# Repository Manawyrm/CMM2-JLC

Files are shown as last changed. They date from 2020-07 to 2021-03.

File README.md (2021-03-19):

Colour Maximite 2 - JLC-ready design
=============================
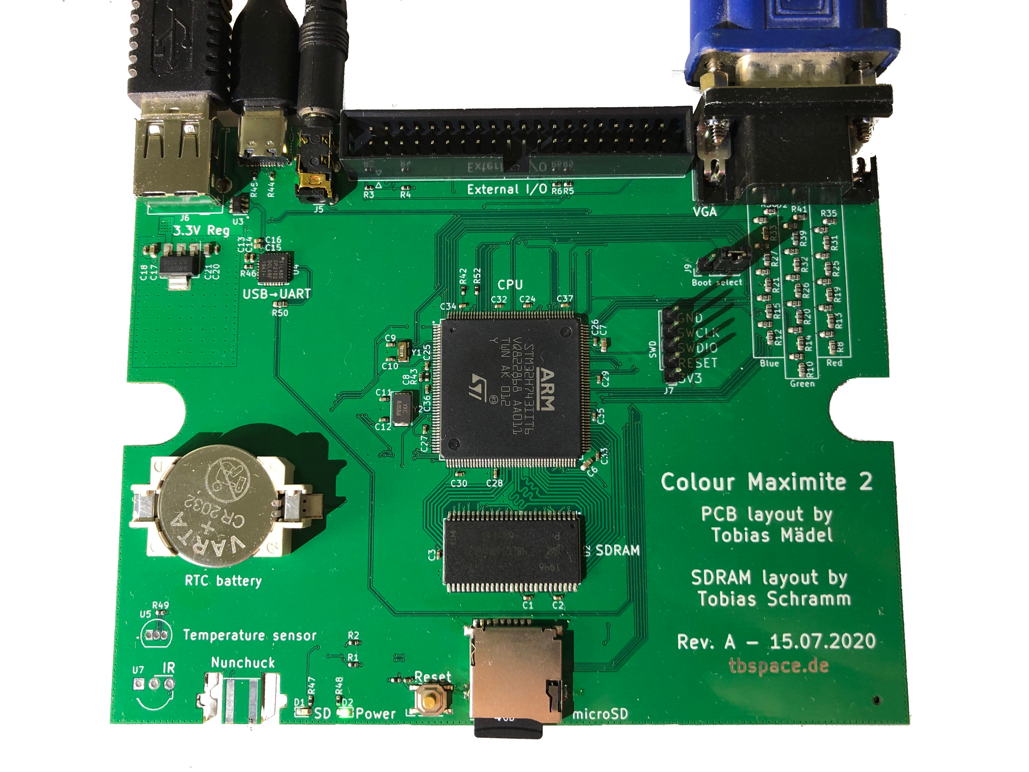
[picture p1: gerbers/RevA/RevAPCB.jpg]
PCB


#### Overview

This is a open-source hardware clone PCB of the [Colour Maximite 2](https://geoffg.net/maximite.html) computer.  
It's fully compatible to the original firmware and software.  

- Designed for automated assembly at [JLCPCB](https://jlcpcb.com/DDE), everything except the connectors can be machine assembled.  
- USB-C port (instead of USB-B) for serial and power  
- microSD socket instead of full-size SD socket  
- STM32 and SDRAM directly onboard, no expensive evaluation board needed  

#### Bill of materials

[Interactive BOM](https://tbspace.de/content/downloads/ibom_cmm2_reve.html)

| Description | Part No.  | Links  |
| :---:|---| -----:|
| 3.5mm audio jack | XKB PJ-3270 | [LCSC](https://lcsc.com/product-detail/Audio-Video-Connectors_XKB-Connectivity-PJ-3270_C381134.html) |
| microSD socket | HOAUC HYC77-TF09-200 | [LCSC](https://lcsc.com/product-detail/Card-Sockets-Connectors_HOAUC-HYC77-TF09-200_C341092.html)  |
| USB-C connector | Jing C167321 | [LCSC](https://lcsc.com/product-detail/USB-Connectors_Jing-Extension-of-the-Electronic-Co-C167321_C167321.html)  |
| USB-A connector | Jing C42650 | [LCSC](https://lcsc.com/product-detail/USB-Connectors_Jing-Extension-of-the-Electronic-Co-C42650_C42650.html)  |
| 40pin IDC | BOOMELE C9138 | [LCSC](https://lcsc.com/product-detail/IDC-Connectors_BOOMELE-Boom-Precision-Elec-C9138_C9138.html)  |
| VGA connector | CONNFLY DS1038-15FBNSiA74-0CC | [LCSC](https://lcsc.com/product-detail/D-Sub-Connectors_CONNFLY-Elec-DS1038-15FBNSiA74-0CC_C75754.html)  |

#### Footprint credits
| Author | Components  |
| ----- |---|
| [Tobias Schramm](https://github.com/TobleMiner) | CR2032 Holder, 3.5mm Audiojack, MicroSD socket, reset button |
| [Jan Henrik Hemsing](https://github.com/Jan--Henrik) | Nunchuck connector |

#### Rev.A Errata
- Missing mounting holes
- SDRAM pinout is missing A12 line 
(causes instability, fixed in Rev.B, workaround with enamelled copper wire of the same length as the other traces)
- SRV05 diode package had the Pin 1 indicator at Pin 6.  
- Nunchuck footprint is reversed

#### Rev. B Errata
- KiCad Bug caused data corruption in PCB files, board files were reset back to pre-RevA state (missing via stitching). Will still work. 
- SRV05 diode package had the Pin 1 indicator at Pin 6.  
- Nunchuck footprint is reversed

#### Rev. C Errata
- SRV05 diode package had the Pin 1 indicator at Pin 6.  
- Nunchuck footprint is reversed

#### Rev. D Errata
- SRV05 diode package had the Pin 1 indicator at Pin 6.

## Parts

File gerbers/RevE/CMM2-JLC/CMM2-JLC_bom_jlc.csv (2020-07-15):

Comment | Designator | Footprint | LCSC Part #
CR2032 | BT1 | BatteryHolder_CR2032-BS-6-1 | C70377
100n | C1,C2,C3,C4,C5,C14,C16,C20,C18,C22,C23,C24,C25,C26,C27,C28,C29,C30,C31,C32,C33,C34,C35,C36,C37 | C_0402_1005Metric | C1525
2.2u | C6,C7 | C_0603_1608Metric | C23630
6p | C9,C10 | C_0402_1005Metric | C30274
20p | C11,C12 | C_0402_1005Metric | C1554
1u | C13,C8,C19 | C_0402_1005Metric | C52923
4.7u | C15 | C_0402_1005Metric | C23733
10u | C17 | C_0603_1608Metric | C19702
22u | C21 | C_0603_1608Metric | C59461
SD CARD / RED | D1 | LED_0603_1608Metric | C2286
POWER / GREEN | D2 | LED_0603_1608Metric | C72043
10k | R1,R2,R3,R4,R5,R6,R42,R52 | R_0402_1005Metric | C25744
240R | R7,R16,R22,R28,R8,R34,R11,R18,R24,R30,R12,R37,R9,R17,R23,R29,R10,R40,R36 | R_0603_1608Metric | C23350
120R | R13,R19,R25,R31,R15,R21,R27,R33,R14,R20,R26,R39,R32,R50 | R_0603_1608Metric | C22787
75R | R35,R38,R41 | R_0603_1608Metric | C4275
10R | R43 | R_0402_1005Metric | C25077
5.1k | R44,R45 | R_0402_1005Metric | C25905
3.3k | R47 | R_0402_1005Metric | C25890
4.7k | R48,R49,R46 | R_0402_1005Metric | C25900
100k | R51 | R_0402_1005Metric | C25741
Reset | SW1 | TS-1187A-X-X-X | C318887
STM32H743IITx | U1 | LQFP-176_24x24mm_P0.5mm | C89597
MT48LC16M16A2P | U2 | TSOP-II-54_22.2x10.16mm_P0.8mm | C26393
SRV05-4 | U3 | SOT-23-6 | C85364
CP2102N-A01-GQFN28 | U4 | QFN-28-1EP_5x5mm_P0.5mm_EP3.35x3.35mm | C6568
AMS1117-3.3 | U6 | SOT-223-3_TabPin2 | C6186
32.768 kHz | Y1 | Crystal_SMD_3215-2Pin_3.2x1.5mm | C32346
8 MHz | Y2 | Crystal_SMD_5032-2Pin_5.0x3.2mm | C115962

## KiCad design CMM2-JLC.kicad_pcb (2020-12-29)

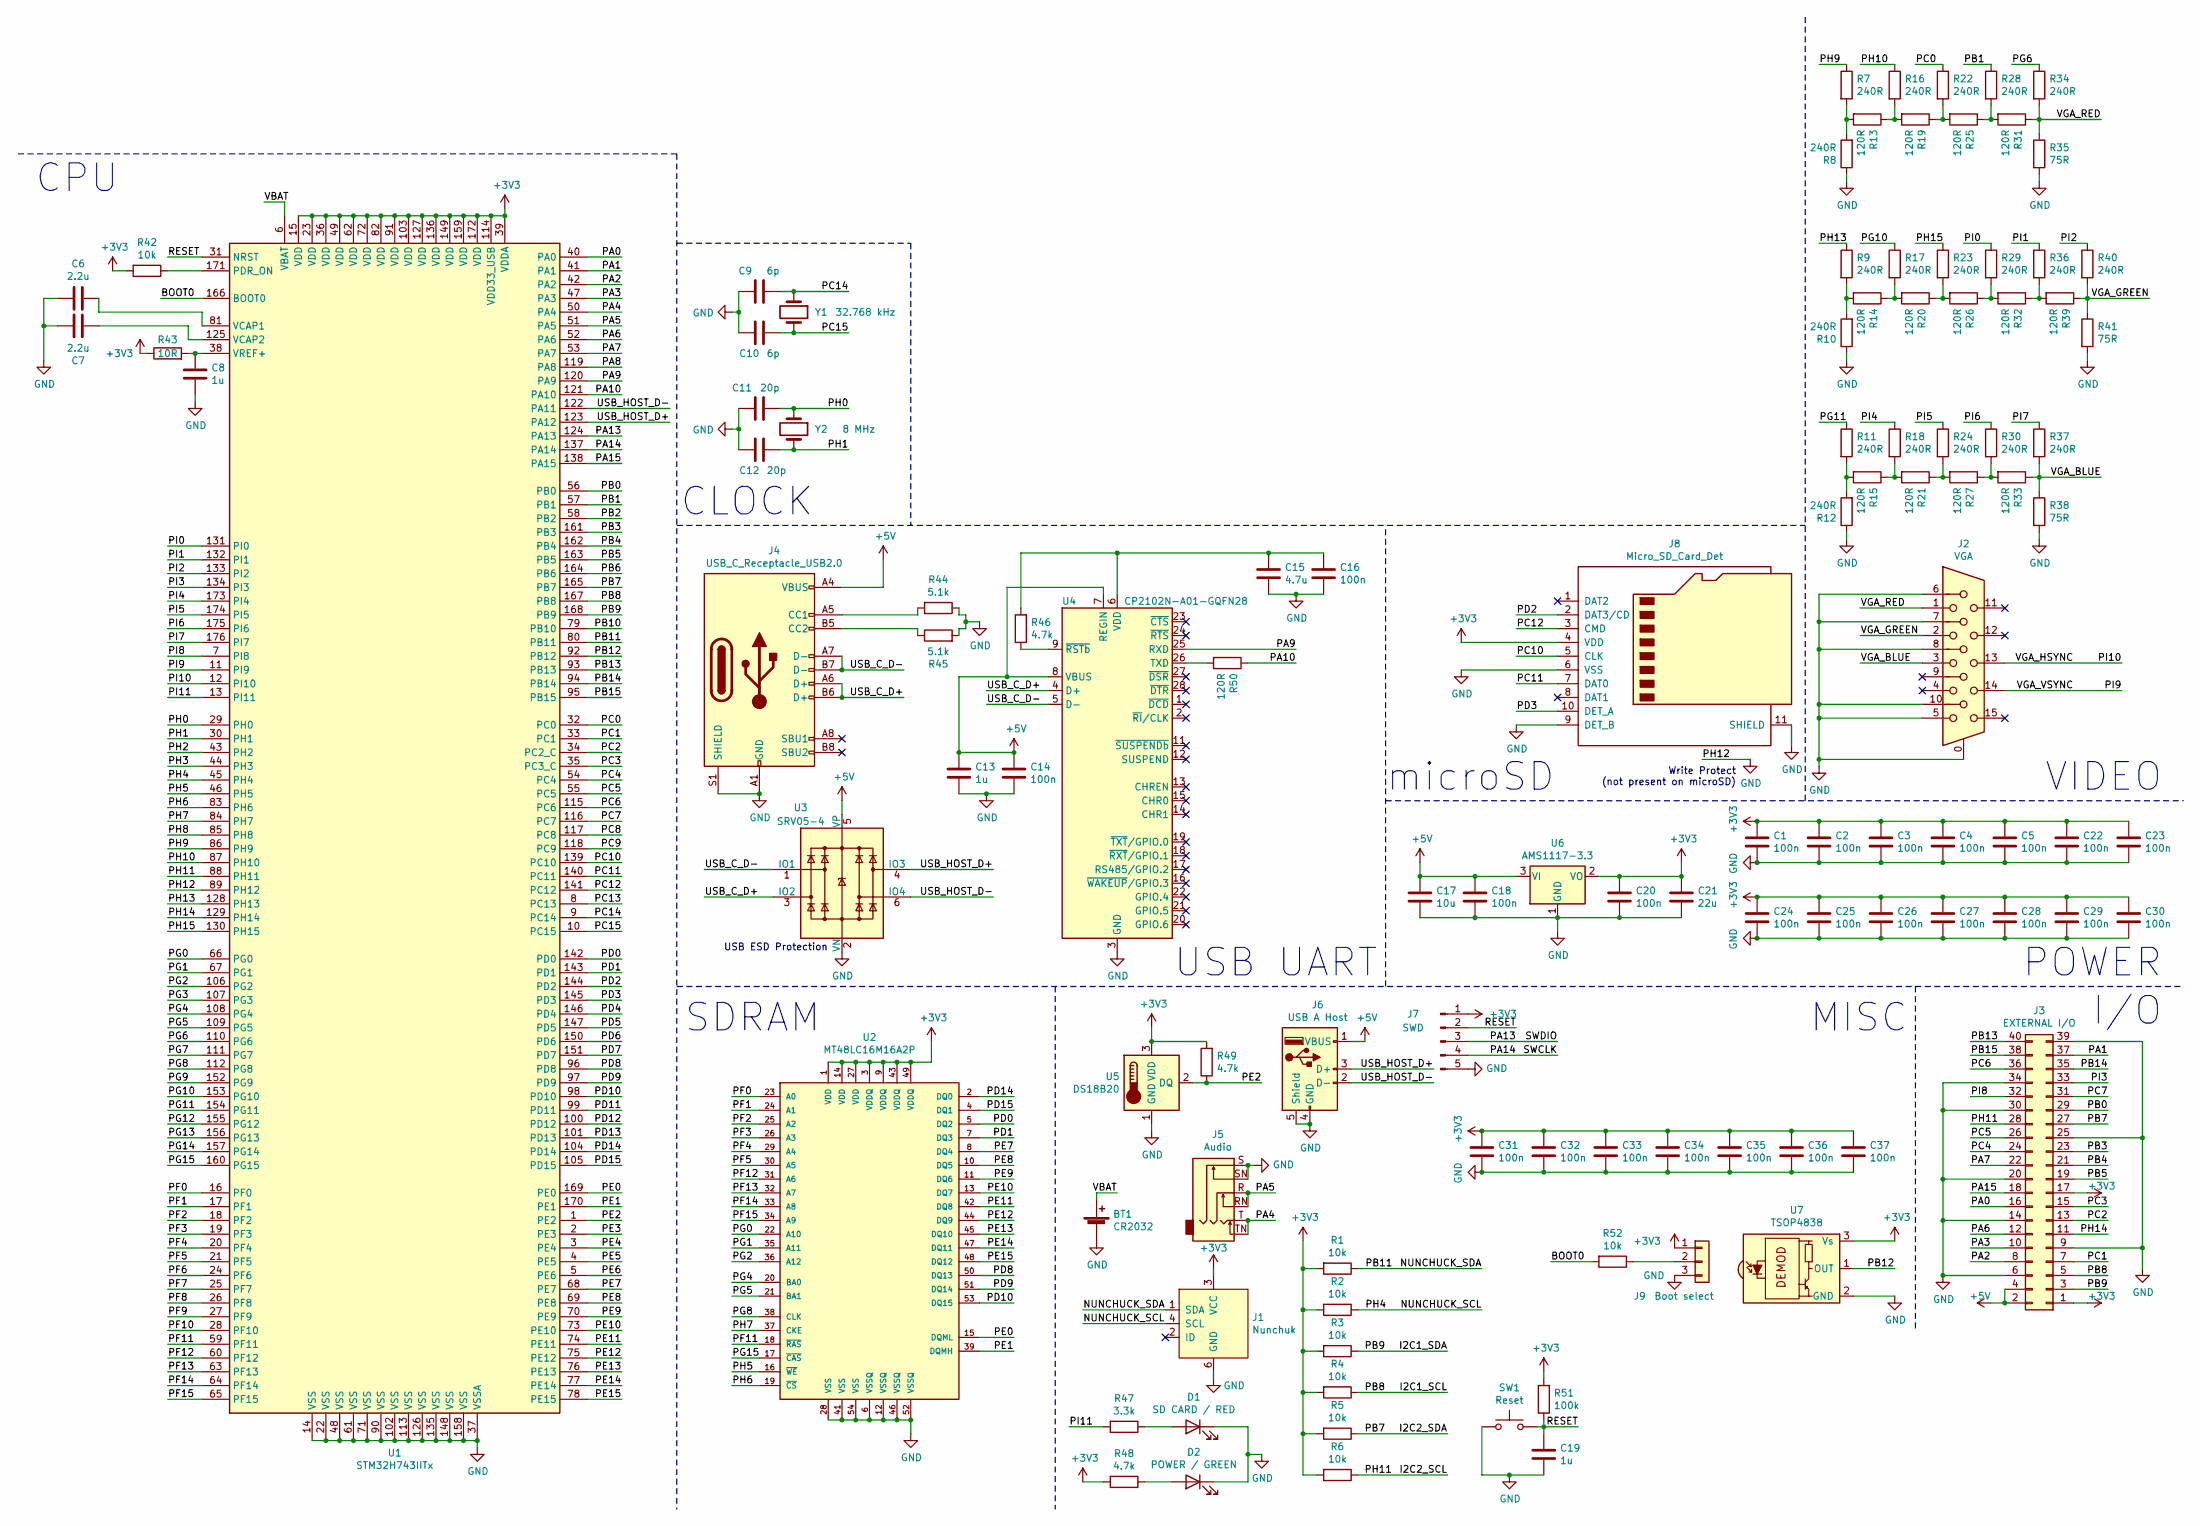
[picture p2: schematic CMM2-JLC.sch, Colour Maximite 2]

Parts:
BT1: CR2032; BatteryHolder_CR2032-BS-6-1; LCSC C70377
C1, C2, C3, C4, C5, C14, C16, C18, C20, C22, C23, C24, C25, C26, C27, C28, C29, C30, C31, C32, C33, C34, C35, C36, C37: 100n; C_0402_1005Metric; LCSC C1525
C6, C7: 2.2u; C_0603_1608Metric; LCSC C23630
C8, C13, C19: 1u; C_0402_1005Metric; LCSC C52923
C9, C10: 6p; C_0402_1005Metric; LCSC C30274
C11, C12: 20p; C_0402_1005Metric; LCSC C1554
C15: 4.7u; C_0402_1005Metric; LCSC C23733
C17: 10u; C_0603_1608Metric; LCSC C19702
C21: 22u; C_0603_1608Metric; LCSC C59461
D1: SD CARD / RED; LED_0603_1608Metric; LCSC C2286
D2: POWER / GREEN; LED_0603_1608Metric; LCSC C72043
J1: Nunchuk; nunchuck
J2: VGA; DSUB-15-HD_Female_Horizontal_P2.29x2,54mm_EdgePinOffset8.63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
J3: EXTERNAL I/O; IDC-Header_2x20_P2.54mm_Vertical
J4: USB_C_Receptacle_USB2.0; USB_C_Receptacle_Palconn_UTC16-G
J5: Audio; PJ-3270
J6: USB A Host; USB_A_Molex_67643_Horizontal
J7: SWD; PinHeader_1x05_P2.54mm_Vertical
J8: Micro_SD_Card_Det; HOAUC_HYC77-TF09-200
J9: Boot select; PinHeader_1x03_P2.54mm_Vertical
R1, R2, R3, R4, R5, R6, R42, R52: 10k; R_0402_1005Metric; LCSC C25744
R7, R8, R9, R10, R11, R12, R16, R17, R18, R22, R23, R24, R28, R29, R30, R34, R36, R37, R40: 240R; R_0603_1608Metric; LCSC C23350
R13, R14, R15, R19, R20, R21, R25, R26, R27, R31, R32, R33, R39, R50: 120R; R_0603_1608Metric; LCSC C22787
R35, R38, R41: 75R; R_0603_1608Metric; LCSC C4275
R43: 10R; R_0402_1005Metric; LCSC C25077
R44, R45: 5.1k; R_0402_1005Metric; LCSC C25905
R46, R48, R49: 4.7k; R_0402_1005Metric; LCSC C25900
R47: 3.3k; R_0402_1005Metric; LCSC C25890
R51: 100k; R_0402_1005Metric; LCSC C25741
SW1: Reset; TS-1187A-X-X-X; LCSC C318887
U1: STM32H743IITx; LQFP-176_24x24mm_P0.5mm; LCSC C89597
U2: MT48LC16M16A2P; TSOP-II-54_22.2x10.16mm_P0.8mm; LCSC C26393
U3: SRV05-4; SOT-23-6; LCSC C85364
U4: CP2102N-A01-GQFN28; QFN-28-1EP_5x5mm_P0.5mm_EP3.35x3.35mm; LCSC C6568
U5: DS18B20; TO-92_Inline
U6: AMS1117-3.3; SOT-223-3_TabPin2; LCSC C6186
U7: TSOP4838; Vishay_MOLD-3Pin
Y1: 32.768 kHz; Crystal_SMD_3215-2Pin_3.2x1.5mm; LCSC C32346
Y2: 8 MHz; Crystal_SMD_5032-2Pin_5.0x3.2mm; LCSC C115962

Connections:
+3V3: C1.1, C2.1, C3.1, C4.1, C5.1, C20.1, C21.1, C22.1, C23.1, C24.1, C25.1, C26.1, C27.1, C28.1, C29.1, C30.1, C31.1, C32.1, C33.1, C34.1, C35.1, C36.1, C37.1, J1.3 (VCC), J3.1, J3.17, J7.1, J8.4 (VDD), J9.1, R1.2, R2.2, R3.2, R4.2, R5.2, R6.2, R42.2, R43.1, R48.2, R49.2, R51.2, U1.15 (VDD), U1.23 (VDD), U1.36 (VDD), U1.39 (VDDA), U1.49 (VDD), U1.62 (VDD), U1.72 (VDD), U1.82 (VDD), U1.91 (VDD), U1.103 (VDD), U1.114 (VDD33_USB), U1.127 (VDD), U1.136 (VDD), U1.149 (VDD), U1.159 (VDD), U1.172 (VDD), U2.1 (VDD), U2.3 (VDDQ), U2.9 (VDDQ), U2.14 (VDD), U2.27 (VDD), U2.43 (VDDQ), U2.49 (VDDQ), U5.3 (VDD), U6.2 (VO), U7.3 (Vs)
+5V: C13.1, C14.1, C17.1, C18.1, J3.2, J3.4, J4.A4 (VBUS), J4.A9 (VBUS), J4.B4 (VBUS), J4.B9 (VBUS), J6.1 (VBUS), U3.5 (VP), U4.7 (REGIN), U4.8 (VBUS), U6.3 (VI)
/BOOT0: R52.2, U1.166 (BOOT0)
/I2C1_SCL: J3.5, R4.1, U1.167 (PB8)
/I2C1_SDA: J3.3, R3.1, U1.168 (PB9)
/I2C2_SCL: J3.28, R6.1, U1.88 (PH11)
/I2C2_SDA: J3.27, R5.1, U1.165 (PB7)
/NUNCHUCK_SCL: J1.4 (SCL), R2.1, U1.45 (PH4)
/NUNCHUCK_SDA: J1.1 (SDA), R1.1, U1.80 (PB11)
/PA0: J3.16, U1.40 (PA0)
/PA1: J3.37, U1.41 (PA1)
/PA2: J3.8, U1.42 (PA2)
/PA3: J3.10, U1.47 (PA3)
/PA4: J5.T, J5.TN, U1.50 (PA4)
/PA5: J5.R, J5.RN, U1.51 (PA5)
/PA6: J3.12, U1.52 (PA6)
/PA7: J3.22, U1.53 (PA7)
/PA8: U1.119 (PA8)
/PA9: U1.120 (PA9), U4.25 (RXD)
/PA10: R50.1, U1.121 (PA10)
/PA13: J7.3, U1.124 (PA13)
/PA14: J7.4, U1.137 (PA14)
/PA15: J3.18, U1.138 (PA15)
/PB0: J3.29, U1.56 (PB0)
/PB1: R28.1, U1.57 (PB1)
/PB2: U1.58 (PB2)
/PB3: J3.23, U1.161 (PB3)
/PB4: J3.21, U1.162 (PB4)
/PB5: J3.19, U1.163 (PB5)
/PB6: U1.164 (PB6)
/PB10: U1.79 (PB10)
/PB12: U1.92 (PB12), U7.1 (OUT)
/PB13: J3.40, U1.93 (PB13)
/PB14: J3.35, U1.94 (PB14)
/PB15: J3.38, U1.95 (PB15)
/PC0: R22.1, U1.32 (PC0)
/PC1: J3.7, U1.33 (PC1)
/PC2: J3.13, U1.34 (PC2_C)
/PC3: J3.15, U1.35 (PC3_C)
/PC4: J3.24, U1.54 (PC4)
/PC5: J3.26, U1.55 (PC5)
/PC6: J3.36, U1.115 (PC6)
/PC7: J3.31, U1.116 (PC7)
/PC8: U1.117 (PC8)
/PC9: U1.118 (PC9)
/PC10: J8.5 (CLK), U1.139 (PC10)
/PC11: J8.7 (DAT0), U1.140 (PC11)
/PC12: J8.3 (CMD), U1.141 (PC12)
/PC13: U1.8 (PC13)
/PC14: C9.2, U1.9 (PC14), Y1.1
/PC15: C10.1, U1.10 (PC15), Y1.2
/PD0: U1.142 (PD0), U2.5 (DQ2)
/PD1: U1.143 (PD1), U2.7 (DQ3)
/PD2: J8.2 (DAT3/CD), U1.144 (PD2)
/PD3: J8.10 (DET_A), U1.145 (PD3)
/PD4: U1.146 (PD4)
/PD5: U1.147 (PD5)
/PD6: U1.150 (PD6)
/PD7: U1.151 (PD7)
/PD8: U1.96 (PD8), U2.50 (DQ13)
/PD9: U1.97 (PD9), U2.51 (DQ14)
/PD10: U1.98 (PD10), U2.53 (DQ15)
/PD11: U1.99 (PD11)
/PD12: U1.100 (PD12)
/PD13: U1.101 (PD13)
/PD14: U1.104 (PD14), U2.2 (DQ0)
/PD15: U1.105 (PD15), U2.4 (DQ1)
/PE0: U1.169 (PE0), U2.15 (DQML)
/PE1: U1.170 (PE1), U2.39 (DQMH)
/PE2: R49.1, U1.1 (PE2), U5.2 (DQ)
/PE3: U1.2 (PE3)
/PE4: U1.3 (PE4)
/PE5: U1.4 (PE5)
/PE6: U1.5 (PE6)
/PE7: U1.68 (PE7), U2.8 (DQ4)
/PE8: U1.69 (PE8), U2.10 (DQ5)
/PE9: U1.70 (PE9), U2.11 (DQ6)
/PE10: U1.73 (PE10), U2.13 (DQ7)
/PE11: U1.74 (PE11), U2.42 (DQ8)
/PE12: U1.75 (PE12), U2.44 (DQ9)
/PE13: U1.76 (PE13), U2.45 (DQ10)
/PE14: U1.77 (PE14), U2.47 (DQ11)
/PE15: U1.78 (PE15), U2.48 (DQ12)
/PF0: U1.16 (PF0), U2.23 (A0)
/PF1: U1.17 (PF1), U2.24 (A1)
/PF2: U1.18 (PF2), U2.25 (A2)
/PF3: U1.19 (PF3), U2.26 (A3)
/PF4: U1.20 (PF4), U2.29 (A4)
/PF5: U1.21 (PF5), U2.30 (A5)
/PF6: U1.24 (PF6)
/PF7: U1.25 (PF7)
/PF8: U1.26 (PF8)
/PF9: U1.27 (PF9)
/PF10: U1.28 (PF10)
/PF11: U1.59 (PF11), U2.18 (~RAS~)
/PF12: U1.60 (PF12), U2.31 (A6)
/PF13: U1.63 (PF13), U2.32 (A7)
/PF14: U1.64 (PF14), U2.33 (A8)
/PF15: U1.65 (PF15), U2.34 (A9)
/PG0: U1.66 (PG0), U2.22 (A10)
/PG1: U1.67 (PG1), U2.35 (A11)
/PG2: U1.106 (PG2), U2.36 (A12)
/PG3: U1.107 (PG3)
/PG4: U1.108 (PG4), U2.20 (BA0)
/PG5: U1.109 (PG5), U2.21 (BA1)
/PG6: R34.1, U1.110 (PG6)
/PG7: U1.111 (PG7)
/PG8: U1.112 (PG8), U2.38 (CLK)
/PG9: U1.152 (PG9)
/PG10: R17.1, U1.153 (PG10)
/PG11: R11.1, U1.154 (PG11)
/PG12: U1.155 (PG12)
/PG13: U1.156 (PG13)
/PG14: U1.157 (PG14)
/PG15: U1.160 (PG15), U2.17 (~CAS~)
/PH0: C11.2, U1.29 (PH0), Y2.1
/PH1: C12.1, U1.30 (PH1), Y2.2
/PH2: U1.43 (PH2)
/PH3: U1.44 (PH3)
/PH5: U1.46 (PH5), U2.16 (~WE~)
/PH6: U1.83 (PH6), U2.19 (~CS~)
/PH7: U1.84 (PH7), U2.37 (CKE)
/PH8: U1.85 (PH8)
/PH9: R7.1, U1.86 (PH9)
/PH10: R16.1, U1.87 (PH10)
/PH13: R9.1, U1.128 (PH13)
/PH14: J3.11, U1.129 (PH14)
/PH15: R23.1, U1.130 (PH15)
/PI0: R29.1, U1.131 (PI0)
/PI1: R36.1, U1.132 (PI1)
/PI2: R40.1, U1.133 (PI2)
/PI3: J3.33, U1.134 (PI3)
/PI4: R18.1, U1.173 (PI4)
/PI5: R24.1, U1.174 (PI5)
/PI6: R30.1, U1.175 (PI6)
/PI7: R37.1, U1.176 (PI7)
/PI8: J3.32, U1.7 (PI8)
/PI9: J2.14, U1.11 (PI9)
/PI10: J2.13, U1.12 (PI10)
/PI11: R47.2, U1.13 (PI11)
/RESET: C19.1, J7.2, R51.1, SW1.2, U1.31 (NRST)
/USB_C_D+: J4.A6 (D+), J4.B6 (D+), U3.3 (IO2), U4.4 (D+)
/USB_C_D-: J4.A7 (D-), J4.B7 (D-), U3.1 (IO1), U4.5 (D-)
/USB_HOST_D+: J6.3 (D+), U1.123 (PA12), U3.4 (IO3)
/USB_HOST_D-: J6.2 (D-), U1.122 (PA11), U3.6 (IO4)
/VBAT: BT1.1 (+), U1.6 (VBAT)
/VGA_BLUE: J2.3, R33.1, R37.2, R38.1
/VGA_GREEN: J2.2, R39.1, R40.2, R41.1
/VGA_RED: J2.1, R31.1, R34.2, R35.1
GND: BT1.2 (-), C1.2, C2.2, C3.2, C4.2, C5.2, C6.2, C7.1, C8.2, C9.1, C10.2, C11.1, C12.2, C13.2, C14.2, C15.2, C16.2, C17.2, C18.2, C19.2, C20.2, C21.2, C22.2, C23.2, C24.2, C25.2, C26.2, C27.2, C28.2, C29.2, C30.2, C31.2, C32.2, C33.2, C34.2, C35.2, C36.2, C37.2, D1.1 (K), D2.1 (K), J1.6 (GND), J2.0, J2.5, J2.6, J2.7, J2.8, J2.10, J3.6, J3.9, J3.14, J3.20, J3.25, J3.30, J3.34, J3.39, J4.A1 (GND), J4.A12 (GND), J4.B1 (GND), J4.B12 (GND), J4.S1 (SHIELD), J5.S, J5.SN, J6.4 (GND), J6.5 (Shield), J7.5, J8.6 (VSS), J8.9 (DET_B), J8.11 (SHIELD), J9.3, R8.1, R10.1, R12.1, R35.2, R38.2, R41.2, R44.1, R45.2, SW1.1, U1.14 (VSS), U1.22 (VSS), U1.37 (VSSA), U1.48 (VSS), U1.61 (VSS), U1.71 (VSS), U1.89 (PH12), U1.90 (VSS), U1.102 (VSS), U1.113 (VSS), U1.126 (VSS), U1.135 (VSS), U1.148 (VSS), U1.158 (VSS), U2.6 (VSSQ), U2.12 (VSSQ), U2.28 (VSS), U2.41 (VSS), U2.46 (VSSQ), U2.52 (VSSQ), U2.54 (VSS), U3.2 (VN), U4.3 (GND), U4.29 (GND), U5.1 (GND), U6.1 (GND), U7.2 (GND)
unnamed: C6.1, U1.81 (VCAP1)
unnamed: C7.2, U1.125 (VCAP2)
unnamed: C8.1, R43.2, U1.38 (VREF+)
unnamed: C15.1, C16.1, R46.2, U4.6 (VDD)
unnamed: D1.2 (A), R47.1
unnamed: D2.2 (A), R48.1
unnamed: J4.A5 (CC1), R44.2
unnamed: J4.B5 (CC2), R45.1
unnamed: J9.2, R52.1
unnamed: R9.2, R10.2, R14.2
unnamed: R11.2, R12.2, R15.2
unnamed: R13.1, R16.2, R19.2
unnamed: R7.2, R8.2, R13.2
unnamed: R14.1, R17.2, R20.2
unnamed: R15.1, R18.2, R21.2
unnamed: R19.1, R22.2, R25.2
unnamed: R20.1, R23.2, R26.2
unnamed: R21.1, R24.2, R27.2
unnamed: R25.1, R28.2, R31.2
unnamed: R26.1, R29.2, R32.2
unnamed: R27.1, R30.2, R33.2
unnamed: R32.1, R36.2, R39.2
unnamed: R42.1, U1.171 (PDR_ON)
unnamed: R46.1, U4.9 (~RSTb)
unnamed: R50.2, U4.26 (TXD)

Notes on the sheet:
SDRAM
CPU
VIDEO
I/O
MISC
USB ESD Protection
USB UART
POWER
Write Protect (not present on microSD)
microSD
CLOCK

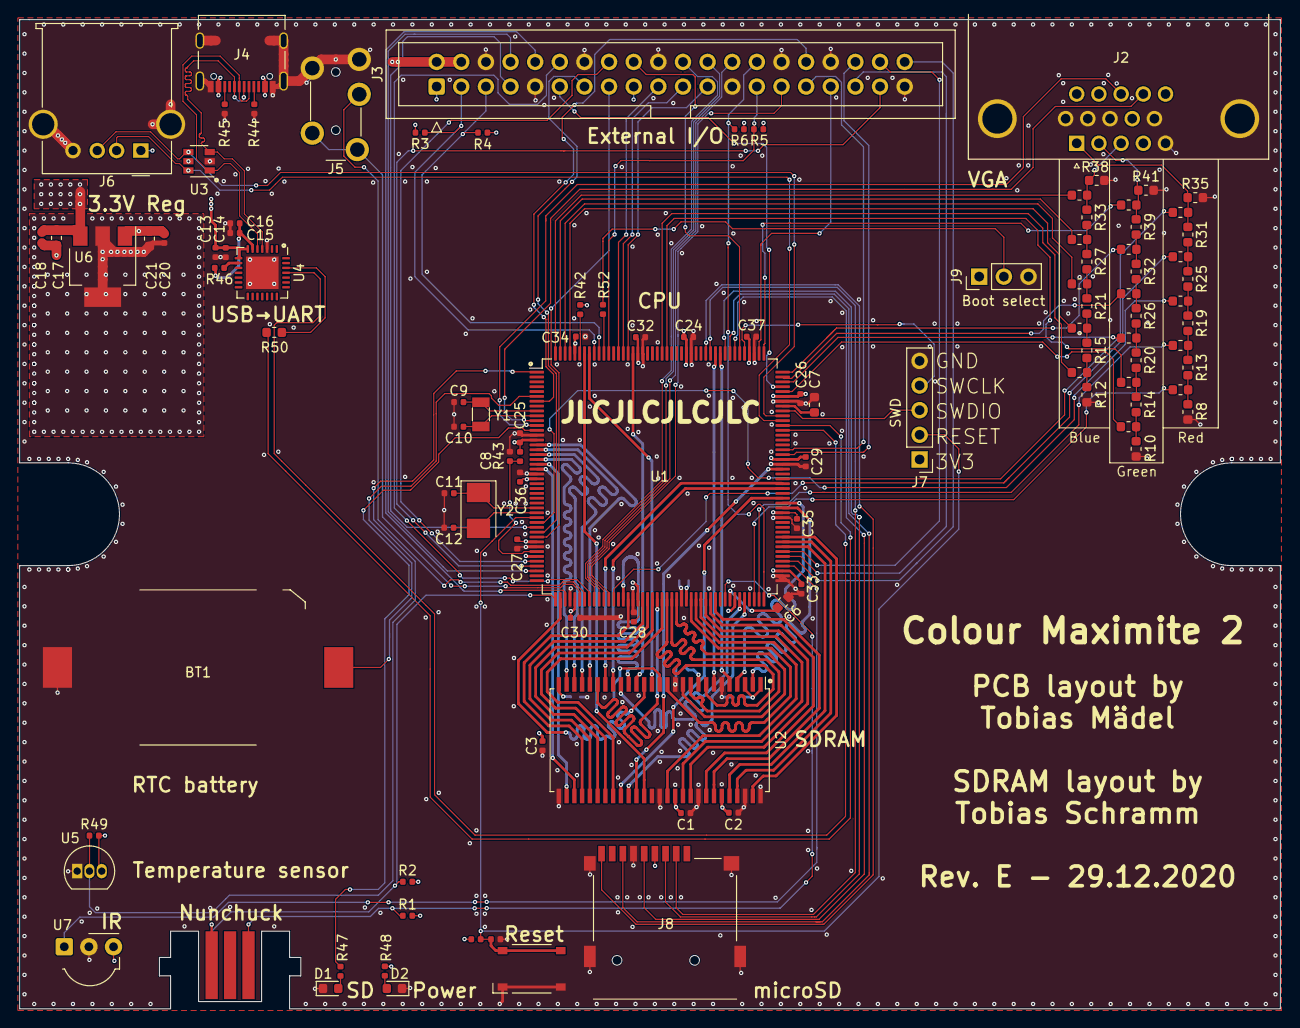
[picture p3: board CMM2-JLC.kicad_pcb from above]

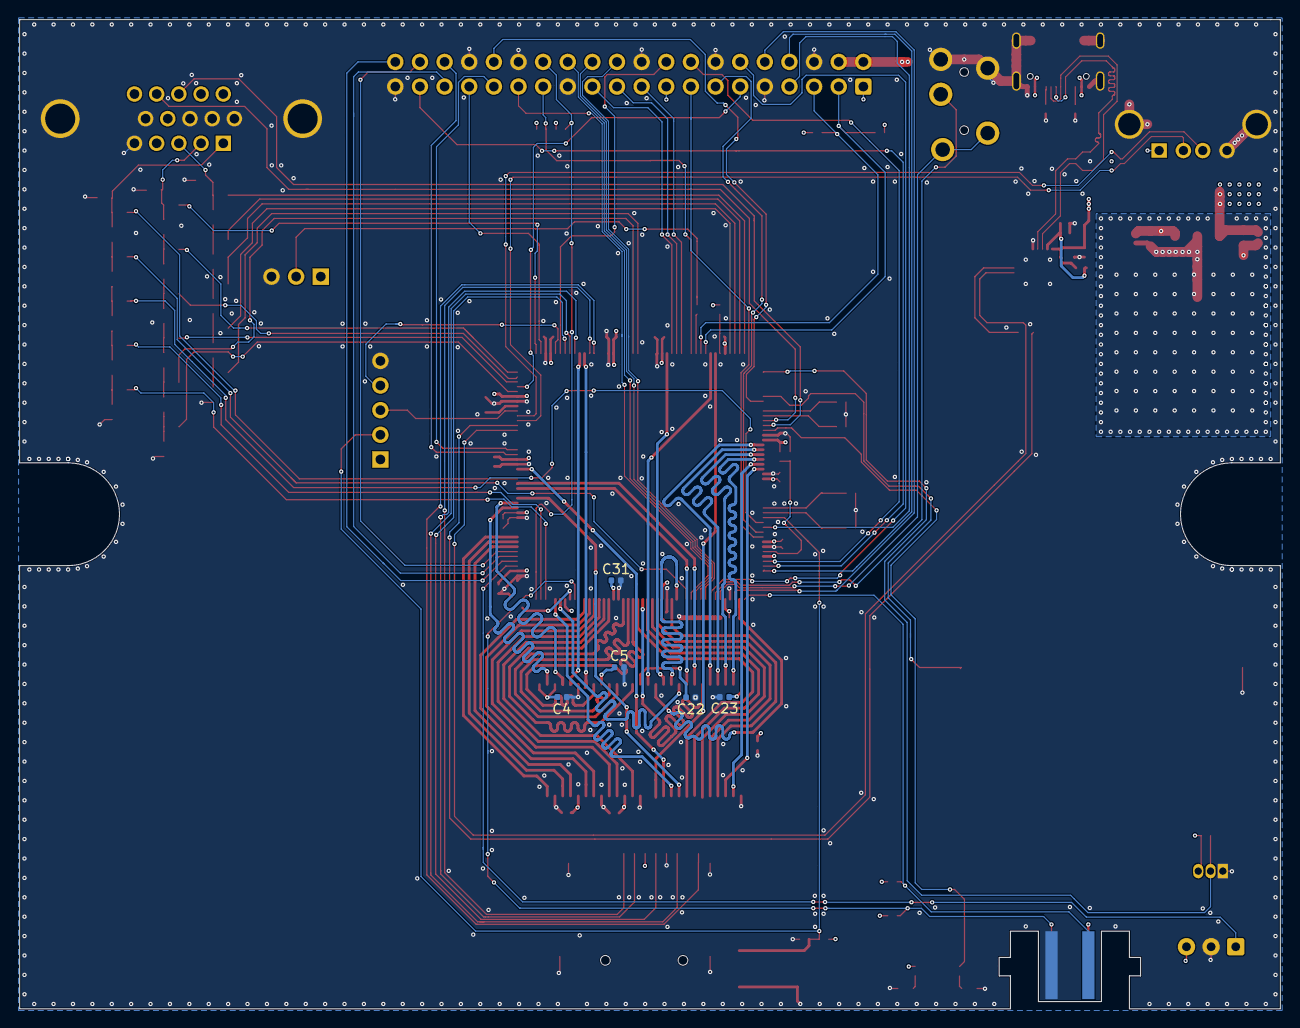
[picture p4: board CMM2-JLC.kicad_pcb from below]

Board: 4 copper layers, 130.0 x 102.0 mm, 111 parts (5 on the bottom side), 143 nets.

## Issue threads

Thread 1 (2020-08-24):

Nunchuck footprint is reversed!

Manawyrm, 2020-08-24:

TobleMiner, 2020-09-07:
Fixed in RevD b2192d67e0b2c5e22a45b95abb56d1f398ac0834

Closed 2020-09-07.

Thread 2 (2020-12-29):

Pin indicator on U3

marcus7070, 2020-12-29:
Firstly, thanks for this project. We've just used it to make our own version. I don't have a clue how to lay out that SDRAM, I'm really appreciative that we could use your work.

On your silkscreen you have a dot that really looks like a pin 1 indicator on U3. I didn't notice it when sending off our files and it looks like JLCPCB did, decided the silk screen was correct, and flipped our U3.

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

Manawyrm, 2020-12-29:
Ooops! Sorry!
I have released Rev.E with fixed silkscreen and released new gerber files.

Thanks for the info!
https://tbspace.de/content/downloads/ibom_cmm2_reve.html

Closed 2021-01-02.

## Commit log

2020-07-05 Add USB-UART, power, microSD
    [CMM2-JLC.sch]
2020-07-05 Add bootstrap circuitry
    [CMM2-JLC.kicad_pcb, CMM2-JLC.sch]
2020-07-05 Add footprints and crystals
    [CMM2-JLC.kicad_pcb, CMM2-JLC.sch]
2020-07-05 Add board outline
    [CMM2-JLC.kicad_pcb]
2020-07-05 first sdram routing
    [CMM2-JLC.kicad_pcb]
2020-07-05 sdram routed
    [CMM2-JLC.kicad_pcb]
2020-07-05 first component routing
    [CMM2-JLC.kicad_pcb, CMM2-JLC.sch]
2020-07-11 before SDRAM re-route
    [CMM2-JLC.kicad_pcb]
2020-07-11 Layout SDRAM
    [CMM2-JLC.kicad_pcb]
2020-07-11 VGA DAC gelayoutet
    [CMM2-JLC.kicad_pcb]
2020-07-11 VGA Routing
    [CMM2-JLC.kicad_pcb]
2020-07-11 Replace VGA connector
    [CMM2-JLC.kicad_pcb, CMM2-JLC.sch]
2020-07-11 USB Host routed
    [CMM2-JLC.kicad_pcb]
2020-07-12 Add decoupling, start routing of 40pin extension header
    [CMM2-JLC.kicad_pcb, CMM2-JLC.sch]
2020-07-14 Add microSD routing
    [CMM2-JLC.kicad_pcb]
2020-07-14 add 40pin expansion header routing
    [CMM2-JLC.kicad_pcb]
2020-07-14 Routed USB, UART and reset pins
    [CMM2-JLC.kicad_pcb, CMM2-JLC.sch]
2020-07-15 Add CP2102 routing
    [CMM2-JLC.kicad_pcb]
2020-07-15 Cleanup silkscreen, add credits
    [CMM2-JLC.kicad_pcb]
2020-07-15 Add pin1 markers and revA gerbers
    [CMM2-JLC-B_Cu.gbl, CMM2-JLC-B_Mask.gbs, CMM2-JLC-B_Paste.gbp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]
2020-07-15 Fix reversed SDRAM bank select and some style/DRC issues
    [CMM2-JLC.kicad_pcb, CMM2-JLC.sch]
2020-07-15 Add final revA gerber
    [CMM2-JLC-B_Cu.gbl, CMM2-JLC-B_Mask.gbs, CMM2-JLC-B_Paste.gbp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]
2020-07-15 Add final-2 revA gerber
    [CMM2-JLC-B_Cu.gbl, CMM2-JLC-B_Mask.gbs, CMM2-JLC-B_Paste.gbp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]
2020-07-31 Rev B: Hook up SDRAM address line A12
    The old sdram symbol did not fit the sdram used. This commit introduces a
    new sdram symbol with address line A12 and bumps the revision to Rev B.
    [CMM2-JLC-B_Cu.gbl, CMM2-JLC-B_Mask.gbs, CMM2-JLC-B_Paste.gbp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]
2020-08-08 Update board
    Last save seems incomplete?!
    [CMM2-JLC.kicad_pcb]
2020-08-11 Rev C
    Some (mostly cosmetic) changes from the final Rev A gerbers were lost in
    Rev B due to a corrupted .kicad_pcb file.
    This revision reintroduces those changes and improves overall attachment
    of groundplanes and islands to one another. Additionally the VGA connector
    footprint has been updated to fit the LCSC connector better.
    Changelog:
    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
    [CMM2-JLC-B_Cu.gbl, CMM2-JLC-B_Mask.gbs, CMM2-JLC-B_Paste.gbp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]
2020-08-24 Rev D
    * Fix 180° rotated Nunchuk connector
    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
    [CMM2-JLC-B_Cu.gbl, CMM2-JLC-B_Mask.gbs, CMM2-JLC-B_Paste.gbp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]
2020-12-29 Fix pin one marker on USB protection diode
    Previously the marker indicated 180 degree rotation of the part.
    [CMM2-JLC.kicad_pcb]
